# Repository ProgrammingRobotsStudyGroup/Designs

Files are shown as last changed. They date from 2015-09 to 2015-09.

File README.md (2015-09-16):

# Designs
Programming Robots Study Group is furnishing this item "as is". Programming Robots Study Group does not provide any warranty of the item whatsoever, whether express, implied, or statutory, including, but not limited to, any warranty of merchantability or fitness for a particular purpose or any warranty that the contents of the item will be error-free. 

In no respect shall Programming Robots Study Group incur any liability for any damages, including, but limited to, direct, indirect, special, or consequential damages arising out of, resulting from, or any way connected to the use of the item, whether or not based upon warranty, contract, tort, or otherwise; whether or not injury was sustained by persons or property or otherwise; and whether or not loss was sustained from, or arose out of, the results of, the item, or any services that may be provided by Programming Robots Study Group. 

We do not accept liabilty for our websites being accurate, complete or up-to-date or for the contents of external links. We distance ourselves expressly from the contents of the linked pages, over the structure of which we have no control. This statement is valid for all of the links on the websites and for all contents of the pages to which the links or banners lead.

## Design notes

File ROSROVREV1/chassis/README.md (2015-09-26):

# Chassis design

*Note:*
Many files in this directory are copyrighted and licensed under the Apache Software License 2.0.  To review this license, please use this link:
http://www.apache.org/licenses/LICENSE-2.0

Files that are licensed under this are listed below:
http://www.apache.org/licenses/LICENSE-2.0

| File Name | URL |
| --- | --- |
| magician_stand.fcstd | https://github.com/ProgrammingRobotsStudyGroup/Designs/blob/master/ROSROVREV1/chassis/magician_stand.fcstd |
| prototype_chassisv1.0.fcstd | https://github.com/ProgrammingRobotsStudyGroup/Designs/blob/master/ROSROVREV2/chassis/prototype_chassisv1.0.fcstd |
| prototype_chassisv2.0.fcstd | https://github.com/ProgrammingRobotsStudyGroup/Designs/blob/master/ROSROVREV2/chassis/prototype_chassisv2.0.fcstd |

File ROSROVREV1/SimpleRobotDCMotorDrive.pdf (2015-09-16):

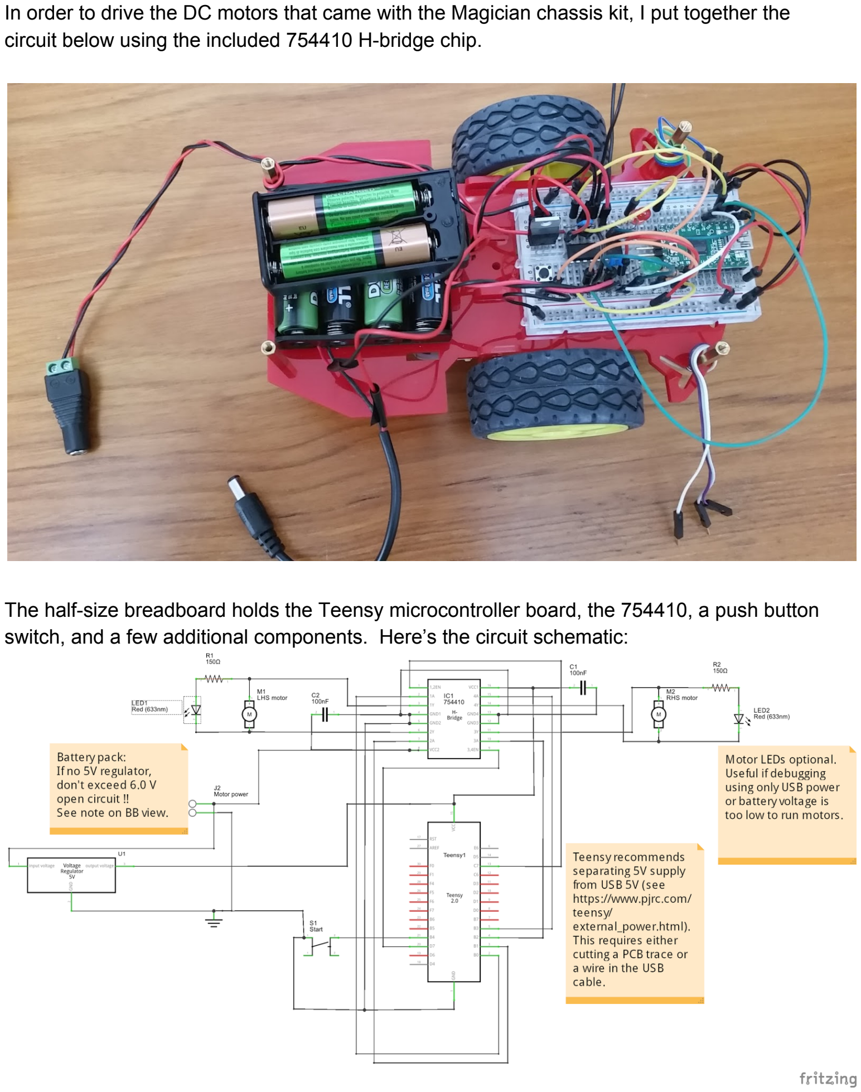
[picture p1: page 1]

In order to drive the DC motors that came with the Magician chassis kit, I put together the circuit below using the included 754410 H-bridge chip.

The halfsize breadboard holds the Teensy microcontroller board, the 754410, a push button switch, and a few additional components. Here’s the circuit schematic:

And here’s the Fritzing view of the breadboard wiring:

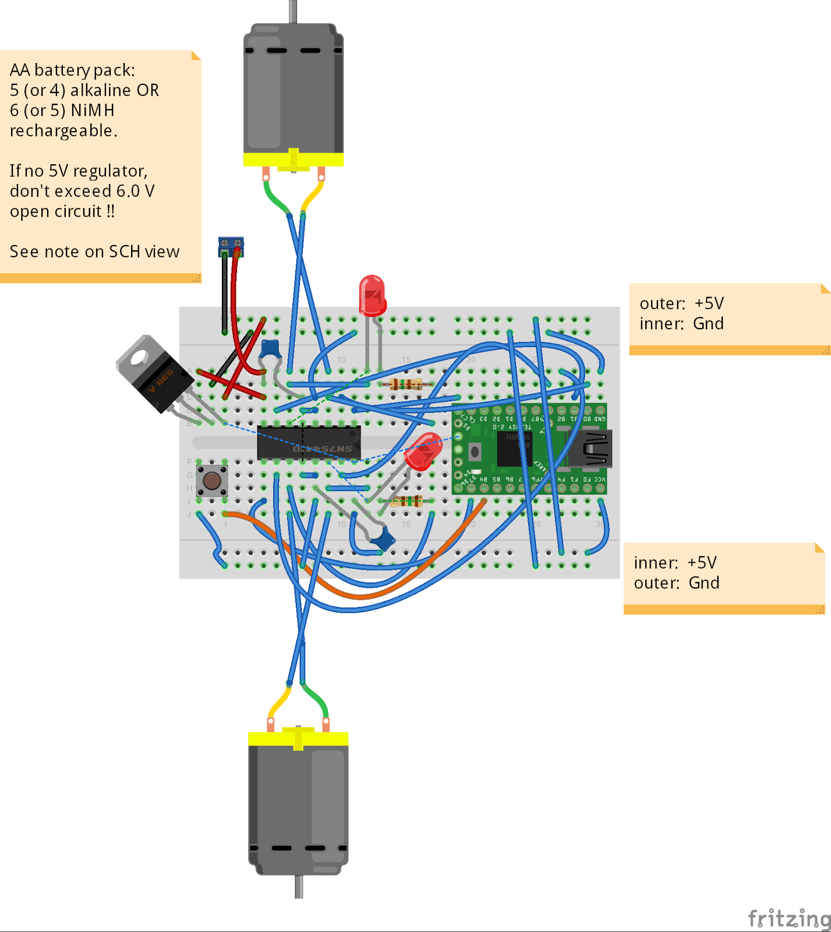
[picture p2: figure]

## Power Supply

I was a little concerned about the battery power supply. At the start I wired up just one motor and jumpered the H-bridge inputs to run it using 4 AA rechargeable (NiMH) batteries to supply about 5.2 V (no load). The motor ran, but the power seemed just enough to overcome the friction in the gearbox. I wanted to increase the motor voltage, but I also knew that supplying too high a voltage to the digital logic would be bad. In particular the Teensy 2.0 schematic (https://www.pjrc.com/teensy/schematic.html) doesn’t include any kind of voltage regulator, so voltages above the rating of the
ATmega32U4 chip would be risky.

Looking at datasheets I found the following ratings:
- ATmega32U4 (https://www.pjrc.com/teensy/atmega32u4.pdf) chip has an Absolute Maximum operating voltage of 6.0V and most datasheet values are obtained at Vcc <= 5.5 V.
- The 754410 (http://www.ti.com/lit/ds/symlink/sn754410.pdf) has an Absolute Maximum of 36V for Vcc1 (the logic supply voltage) but the datasheet recommends 5.5V max.
- The motors that came with the kit appear (https://www.sparkfun.com/products/12866) to be rated at 6.0 V max with a
recommended (http://cdn.sparkfun.com/datasheets/Robotics/DG01D.pdf) voltage of 4.5V.

I wanted to use rechargeable batteries, but when I measured the voltages in the table below, I found that 4 AA NiMH batteries would supply < 3 V to the motor and only 4.7 V to the logic. Alkaline batteries provided > 6.0 V so I didn’t want to risk the Teensy by using this for logic power.

Without a voltage regulator

Battery config | No load battery voltage (V) | Battery voltage (V) one motor running | Motor voltage (V) one motor running | Motor Speed
4x NiMH AA | 5.1 | 4.7 | 2.95 | Slow; expected to be worse with two motors running
4x Alkaline AA | 6.27 | | | Didn’t try

Next I added an additional AA battery holder in series with the original 4-cell holder so I could use 5 or 6 cells in series. I also added a 7805 voltage regulator to the breadboard to provide 5 V for logic power, while I used the full battery voltage for the Vcc2 input to the 754410 H-bridge chip. Measuring voltages with this configuration gave the table below.

With a voltage regulator for logic 5 V power

Battery config | No load battery voltage (V) | Logic voltage (V) motor off | Logic voltage (V) one motor running | Motor voltage (V) one motor running | Motor speed
4x Alkaline AA | 6.27 | 4.63 | 4.09 | 3.78 | Medium

5x Alkaline AA | 7.77 | 4.97 | 4.96 | 5.12 | Fast
5x NiMH AA | 6.39 | 4.84 | 4.44 | 4.11 | Medium
6x NiMH AA | 7.68 | 4.96 | 4.96 | 5.25 | Fast

I concluded it was best to use the regulator with either 6 rechargeable AA or 5 alkaline AA batteries. Things would probably be functional with 5 NiMH or 4 alkaline cells but the motor would run slower and the logic voltage would be on the low side. I made the measurements above with only one motor running the voltages will likely be a bit lower when both motors run simultaneously.

## Teensy Conflict Between USB Power and Battery Power

The Teensy site recommends (https://www.pjrc.com/teensy/external_power.html) separating the USB power from an external power source used to power Teensy Vcc. Three possible modifications are suggested on that site. Some possible scenarios to avoid the conflict between USB power and external power:
1. Make no mods, but remember (every time!) to disconnect the USB cable before connecting the battery. And vice versa. Personally I doubt that I would remember this every time.
2. Make one of the first two mods recommended by Teensy (either cut the PCB trace or cut the USB wire). This always avoids the conflict, but means that the battery must always be connected to power the Teensy (even when uploading code).
3. Make the third mod suggested by Teensy which powers the Teensy from the USB power if no battery is connected. The disadvantage is that you have to solder one diode to the Teensy PCB and add another diode in series with the battery connection. Also, the drop across the diode will reduce the available voltage.

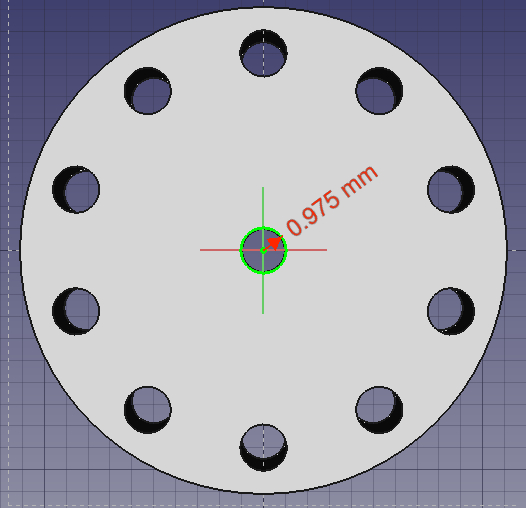
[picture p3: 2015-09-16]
ROSROVREV1/wheel_encoder_2.jpg

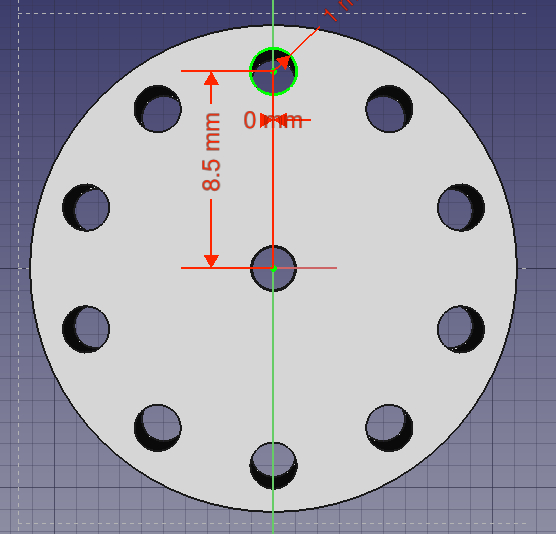
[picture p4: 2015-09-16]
ROSROVREV1/wheel_encoder_1.jpg

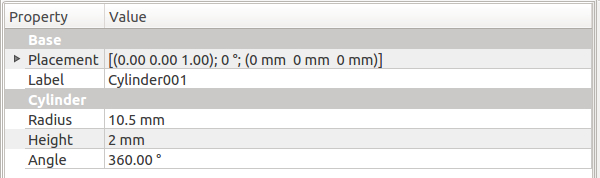
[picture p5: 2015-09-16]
ROSROVREV1/wheel_encoder_3.jpg

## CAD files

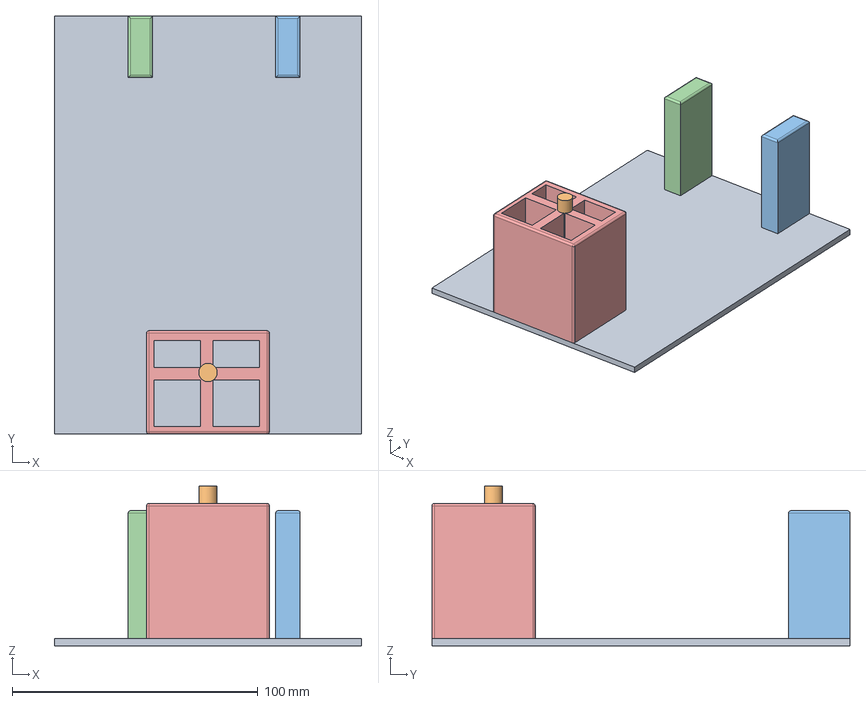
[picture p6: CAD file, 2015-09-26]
ROSROVREV1/chassis/magician_stand.fcstd
125.0 x 170.0 x 65.0 mm

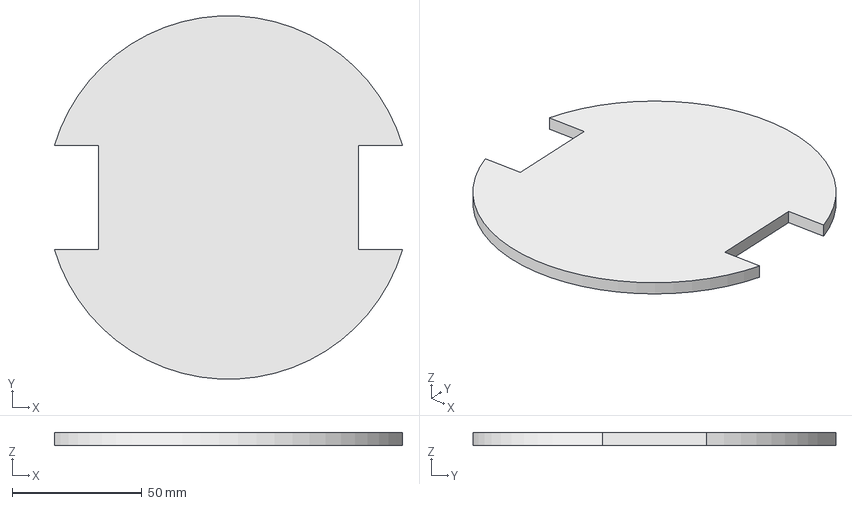
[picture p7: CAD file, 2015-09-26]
ROSROVREV2/chassis/prototype_chassisv1.0.fcstd
134.2 x 139.8 x 5.00 mm

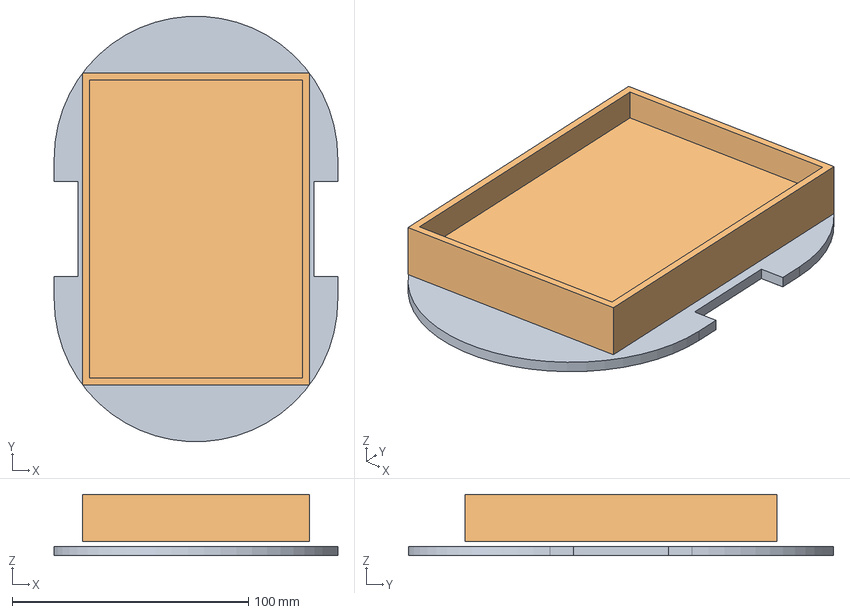
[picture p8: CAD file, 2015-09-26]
ROSROVREV2/chassis/prototype_chassisv2.0.fcstd
120.0 x 179.8 x 26.0 mm

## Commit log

2015-09-16 Add Patrick's PDF which describes the circuit. Add Patrick's original Fritzing Diagram.
    [Teensy DC motor driver.fzz]
2015-09-16 Revised Motor Driver.
    [Teensy DC motor driver_2.fzz]
2015-09-16 Add wheel encoder.
    [Teensy DC motor driver_2.fzz]
2015-09-16 Wheel encoder design.
2015-09-16 Work on schematic.
    [Teensy DC motor driver_2.fzz]
2015-09-16 Chassis design directory.
2015-09-17 Initial commit of prototype chassis
    [prototype_chassisv1.0.fcstd]
2015-09-26 Adding v2.0 chassis and magician chassis stand Added copyright and license informationt to designs
    [magician_stand.fcstd, prototype_chassisv2.0.fcstd]
2015-09-26 adding license and copyright information
    [prototype_chassisv1.0.fcstd]
2015-09-26 1. Clean up design. 2. Work on schematic. 3. Work on board layout.
    [Teensy DC motor driver_2.fzz]
2015-09-26 updating location of magician_stand.fcstd and setting up README.md in new location
    [magician_stand.fcstd]
